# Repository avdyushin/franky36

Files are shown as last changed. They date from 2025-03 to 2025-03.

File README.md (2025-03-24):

# Franky36

Franky36 is 36 key compact handwired split keyboard.
It uses RP2040-Zero controller and QMK firmware.

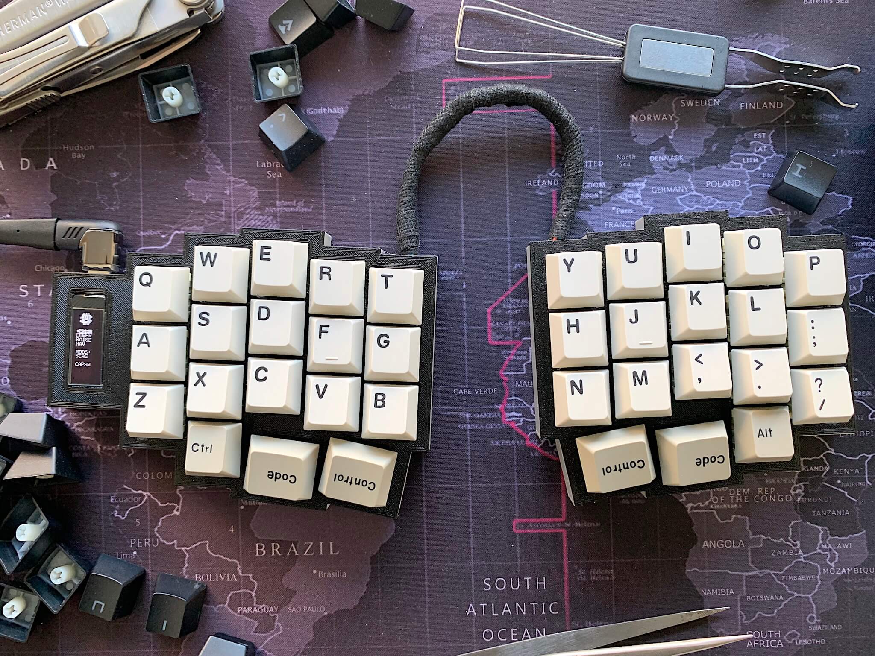
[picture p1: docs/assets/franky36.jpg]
franky36


GMK 9009 clone PBT keycaps are used in the photo.

## Features

- Split with single controller
- QMK (fully customizable)
- VIA support
- OLED display with layer status
- USB-C

## Layout

The default layout is similar to the Planck layout.

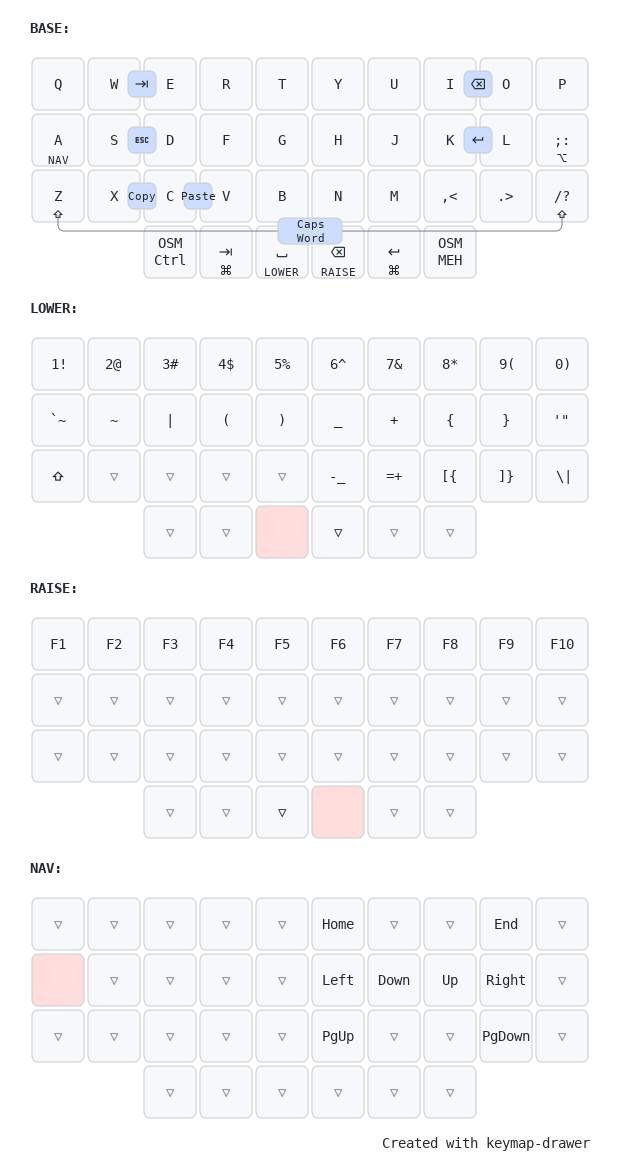
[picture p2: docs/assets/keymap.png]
layout


## Bill Of Material

| Item | Quantity |
|---|---|
| 3D printed case parts | 6 |
| RP2040-Zero controller | 1 |
| MX switches | 36 |
| Through hole 1N4148 diodes | 36 |
| OLED 128x32 SSD1306 display | 1 |
| 1u keycaps | 32 |
| 1.25u keycaps | 4 |
| Electrical wires | |
| Magnetic USB-C adapter (optional) | 1 |
| Foam | 1 |

## Case and Plate

Designed in OpenSCAD and 3D printed. See [case](./case) for STL files and OpenSCAD source.

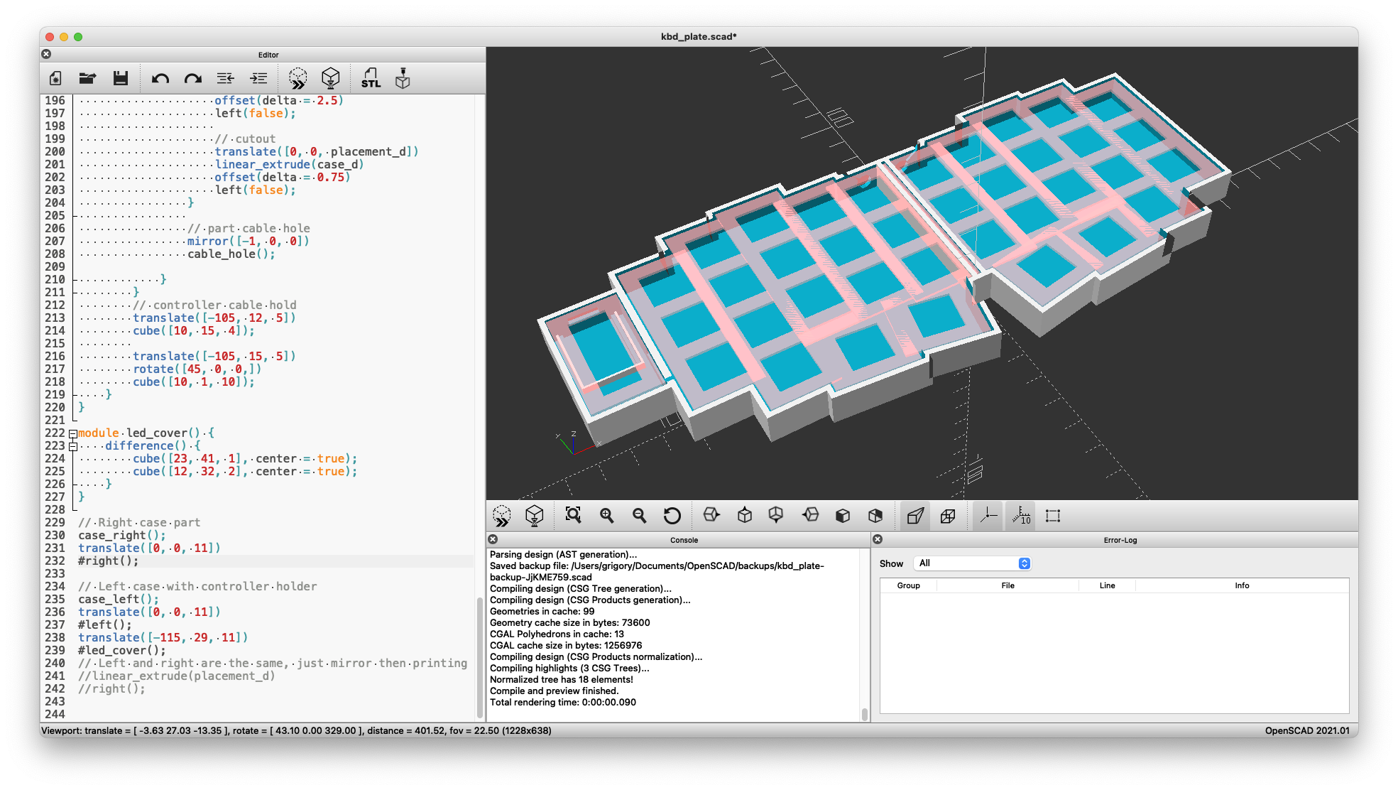
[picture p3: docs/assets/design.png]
case


## Assembly

Assembling the Franky36 keyboard involves several steps that require attention to detail and precision.
This guide will walk you through each step of the process.
Before starting, make sure you have all the necessary components and tools listed in the Bill of Material section.

### Pinout

Rows and columns are connected to the RP2040-Zero controller as follows:

Columns: `GP9`, `GP10`, `GP11`, `GP12`, `GP13`, `GP14`, `GP15`, `GP26`, `GP27`, `GP28`

Rows: `GP5`, `GP4`, `GP3`, `GP2`

Display: `GP0` (SDA), `GP1` (SCL), `GND`, `3v3`

### Steps

1. Begin by printing case parts, plates, and covers. Ensure that the prints are accurate and fit together properly.
1. Insert the MX switches into the designated slots on the plates. Make sure each switch is securely in place.
1. Solder the through-hole 1N4148 diodes to the switches. This step is crucial for the proper functioning of the keyboard matrix.
1. Attach electrical wires to the switches. These wires will connect the switches to the controller.
1. Insert foam into the case to provide cushioning and reduce noise.
1. Carefully place the plates with the switches into the case, ensuring they fit snugly.
1. Connect the wires from the matrix to the RP2040-Zero controller by soldering them in place.
1. Solder OLED 128x32 SSD1306 display to the controller.
1. Secure the RP2040-Zero controller inside the case with hot glue.
1. Upload the QMK firmware to the controller.
1. Test the keyboard to ensure all keys and the OLED display are working as expected.
1. Place the cover on the case, carefuly put display into cutout.
1. Finally, place the keycaps.

## Firmware

QMK with VIA support. See [firmware](./firmware) folder for firmware binary files.

Source code is available in the [QMK firmware repository](https://github.com/qmk/qmk_firmware/tree/master/keyboards/handwired/franky36).

### QMK Configurator

You can use the [QMK Configurator](https://config.qmk.fm/#/handwired/franky36/LAYOUT) to create your custom keymap.

### VIA

Keymap with VIA support is available in the [QMK userspace repository](https://github.com/avdyushin/qmk_userspace_via/tree/franky36).

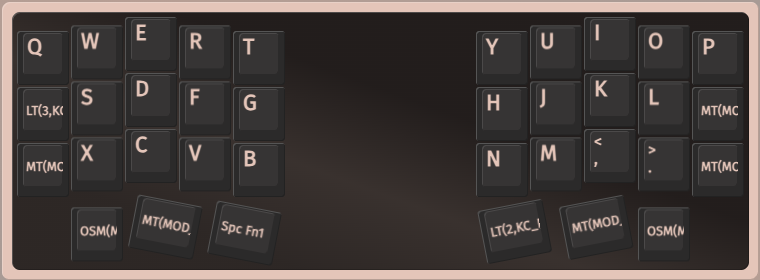
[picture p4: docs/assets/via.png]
via


VIA keyboard definition file is available in the [VIA repository](https://github.com/avdyushin/keyboards/tree/franky36/v3/handwired/franky36)

> NOTE: To make VIA export work in Brave browser enable File System Access API: brave://flags/#file-system-access-api

## Links

- [QMK](https://qmk.fm/)
- [VIA](https://caniusevia.com/)

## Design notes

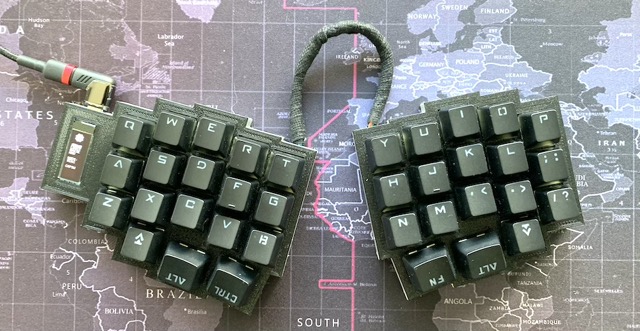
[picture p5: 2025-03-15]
docs/assets/completed.jpeg

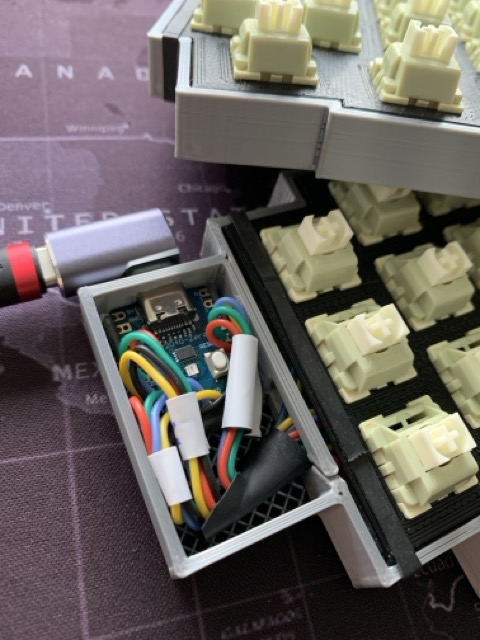
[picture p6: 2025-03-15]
docs/assets/case.jpeg

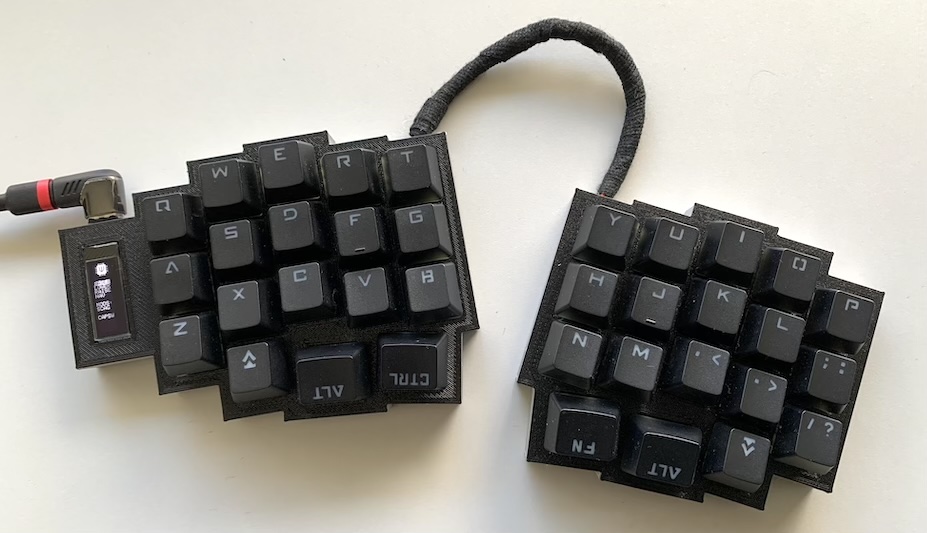
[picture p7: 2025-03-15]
docs/assets/franky36_black.jpg

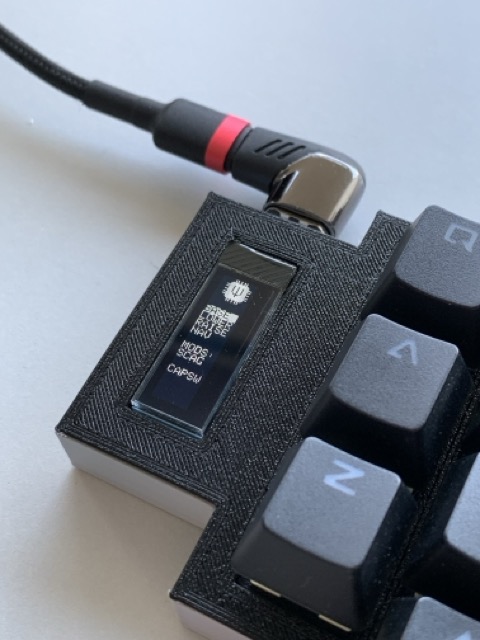
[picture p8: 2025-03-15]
docs/assets/display.jpeg

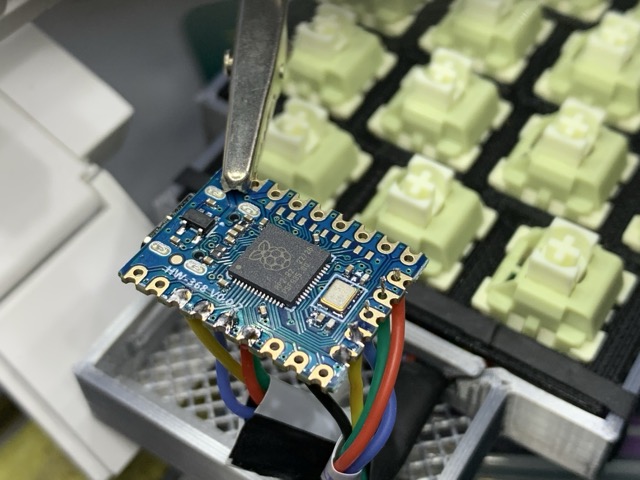
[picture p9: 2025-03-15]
docs/assets/controller.jpeg

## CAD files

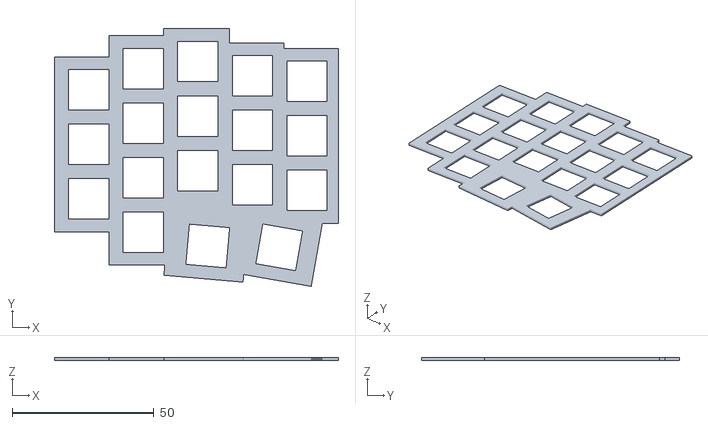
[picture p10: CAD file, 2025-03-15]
case/plate_left.stl
100.2 x 91.0 x 1.00

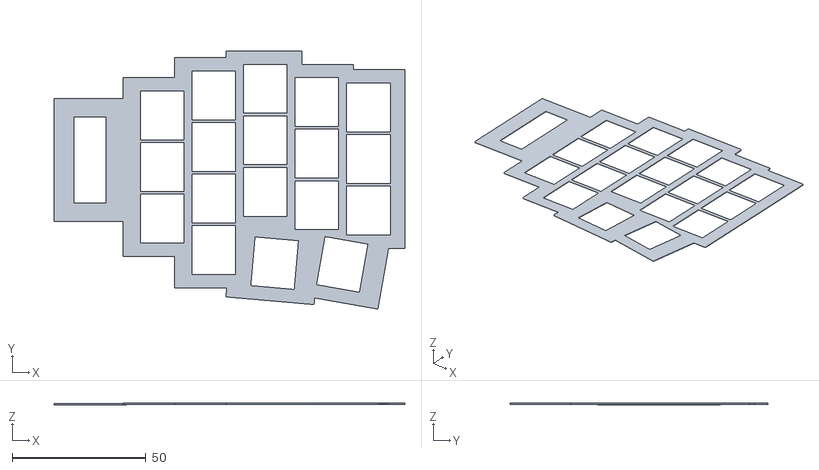
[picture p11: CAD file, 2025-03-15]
case/cover_left.stl
131.0 x 96.4 x 0.59

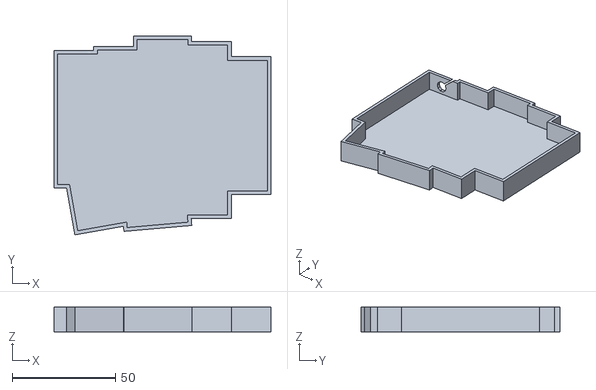
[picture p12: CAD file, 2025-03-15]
case/case_right.stl
105.2 x 96.4 x 12.0

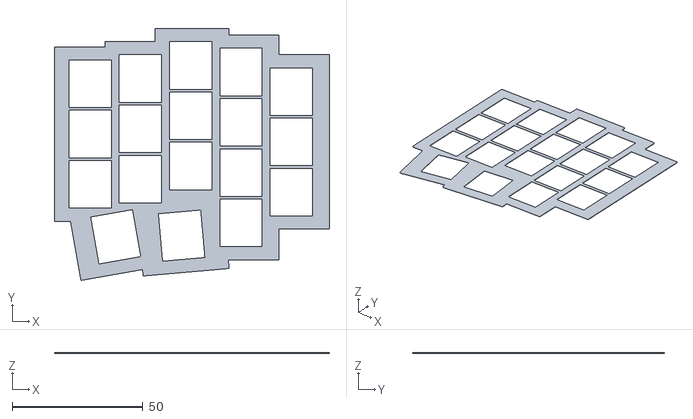
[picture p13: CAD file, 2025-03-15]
case/cover_right.stl
105.2 x 96.4 x 0.56

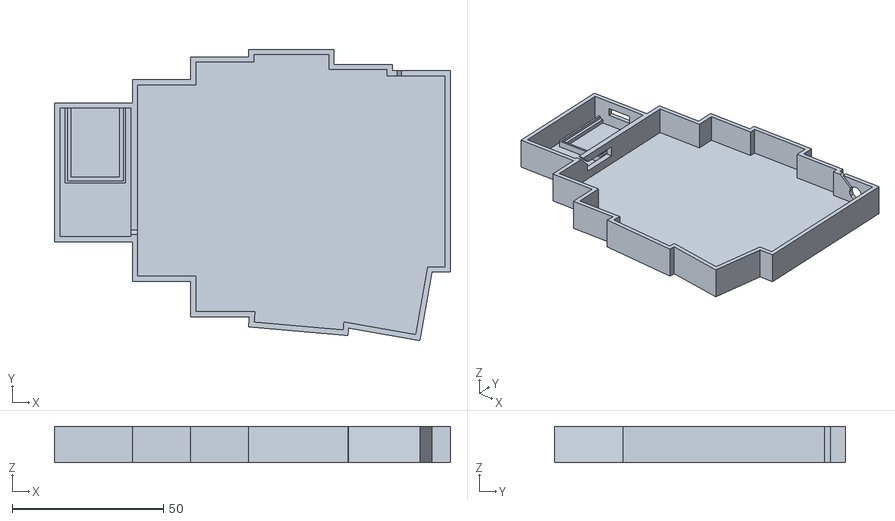
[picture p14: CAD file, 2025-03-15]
case/case_left.stl
131.0 x 96.4 x 12.0

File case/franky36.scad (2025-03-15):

mx_w = 14.25;
mx_h = 14.25;
mx_d = 10;

col_keys_count = 3;
col_keys_spacing_w = 2.5;
col_keys_spacing_h = 2.5;

placement_w = mx_w + col_keys_spacing_w * 2;
placement_h = mx_h + col_keys_spacing_h * 2;
placement_d = 1.5;
placement_padding = 2;

case_d = 12;

_1U = 1.0;
_1_25U = 1.25;

pro_micro_w = 18;
pro_micro_h = 33;

micro_usb_w = 8;
micro_usb_h = 3;

rp2040_zero_w = 18.5;
rp2040_zero_d = 24.5;
rp2040_zero_h = 1.5;

usb_c_w = 10;
usb_c_h = 3;

module switch_cutout() {
    square([mx_w, mx_h]);
}

module over_switch_cutout() {
    translate([-1, -2, 0])
    square([mx_w + 2, mx_h + 4]);
}

module switch_cuts_only(count, col_w) {
    dx0 = placement_padding + (col_w / 2 - (placement_w / 2));
    dy0 = placement_padding;
    
    
    translate([dx0, dy0])
    for (i = [0:1:count - 1]) {
        dy = col_keys_spacing_h + placement_h * i;
        translate([0, dy, 0])
            children();
    }
}

module keys_col(count, size = _1U, extra_pad = 0, offset_delta = 0) {
    col_h = count * placement_h + placement_padding * 2;
    col_w = placement_w * size + placement_padding * 2;

    if (offset_delta > 0) {
        switch_cuts_only(count, col_w) children();
    } else {
        difference() {
            union() {
                square([col_w, col_h]);
                
                // plug the hole
                translate([0, -extra_pad])
                square([col_w, extra_pad]);
            }
            switch_cuts_only(count, col_w) children();
        }
    }
}

module rows(offset_delta = 0) {
    row_offsets = [-2, 0, 5, 2.5 - placement_h, -5];
    col_counts = [3, 3, 3, 4, 3];
    extra_pads = [0, 0, 5, 0, 0];
    rows_count = len(row_offsets);

    for (i = [0:1:rows_count - 1]) {
        dx0 = placement_w * i;
        dy0 = row_offsets[i];
        count = col_counts[i];
        pad = extra_pads[i];
        translate([dx0, dy0, 0])
            keys_col(count, _1U, pad, offset_delta) children();
    }
}

module shift_key(offset_delta = 0) {
    translate([placement_w / 2, -placement_h - placement_padding * 2.5, 0])
    rotate([0, 0, 10])
    keys_col(1, _1_25U, 0, offset_delta) children();
}


module layer_key(offset_delta = 0) {
    translate([placement_w * 1.75, -placement_h - placement_padding * 1.75, 0])
    rotate([0, 0, 5])
    keys_col(1, _1_25U, 0, offset_delta) children();
}

module half(offset_delta = 0) {
    rows(offset_delta) children();
    shift_key(offset_delta) children();
    layer_key(offset_delta) children();
}

module left_plate(offset_delta = 0) {
    mirror([-1, 0, 0])
    half(offset_delta) children();
}

module right_plate(offset_delta = 0) {
    half(offset_delta) children();
}

module cable_hole() {
    union() {
        translate([placement_w / 2 - 2, placement_h * 3 + 10, 6])
        rotate([90, 0, 0])
        cylinder(h = 10, r = 3);
        
        rotate([0, 50, 0])
        translate([placement_w / 2 - 10, placement_h * 3, 10])
        cube([1, 15, 10]);
    }
}

module case_right() {
    
    difference() {
        difference() {
            // base
            linear_extrude(case_d)
            offset(delta = 2.5)
            right_plate();
            
            // cutout
            translate([0, 0, placement_d])
            linear_extrude(case_d)
            offset(delta = 0.75)
            right_plate();
        }
        
        // cable hole
        cable_hole();
    }
}

module plate() {
    cube([rp2040_zero_w, rp2040_zero_d, rp2040_zero_h]);
}

module plate_holder() {
    difference() {
        cube([20, 25, 4]);
        translate([2, -1, -0.5])
        cube([16, 24, 5]);
        translate([0.75, -0.25, 3]) plate();
    }
}

module controller_case() {
    
    c_w = pro_micro_w + placement_padding * 2;
    c_h = pro_micro_h + placement_padding * 4;
    
    difference() {
        // base
        linear_extrude(case_d)
        offset(delta = 2.5)
        square([c_w, c_h]);
        
        // cutout
        translate([0, 0, placement_d])
        linear_extrude(case_d)
        offset(delta = 0.75)
        square([c_w, c_h]);
        
        // usb hole
        translate([c_w / 2 - usb_c_w / 2, c_h, 6])
        cube([usb_c_w, 5, usb_c_h]);
    }
    rotate([0, 0, 180])
    translate([-21, -42, 0])
        plate_holder();
}


module case_left() {
    difference() {
        union() {
            translate([-126, 8, 0])
            controller_case();
            difference() {
                difference() {
                    // base
                    linear_extrude(case_d)
                    offset(delta = 2.5)
                    left_plate();
                    
                    // cutout
                    translate([0, 0, placement_d])
                    linear_extrude(case_d)
                    offset(delta = 0.75)
                    left_plate();
                }
                
                // part cable hole
                mirror([-1, 0, 0])
                cable_hole();

            }
        }
        // controller cable hold
        translate([-105, 12, 5])
        cube([10, 15, 4]);
        
        translate([-105, 15, 5])
        rotate([45, 0, 0,])
        cube([10, 1, 10]);
    }
}

module led_cover(h) {
    difference() {
        cube([23, 41, h], center = true);
        cube([12, 32, h * 2], center = true);
    }
}

module led_top_cover(h) {
    difference() {
        cube([27, 46, h], center = true);
        cube([12, 32, h * 2], center = true);
    }

}

module right_top_cover() {
    difference() {
        linear_extrude(4)
        offset(delta = 5)
        right_plate();
        translate([0, 0, -1])
        linear_extrude(4)
        offset(delta = 3.5)
        right_plate();
        
        translate([0, 0, 1])
        linear_extrude(4)
        right_plate(offset_delta = 1) over_switch_cutout();
    }
}

module right_top_cover_v2(h) {
    difference() {
        linear_extrude(h)
        offset(delta = 2.5)
        right_plate();
        
        translate([0, 0, -1])
        linear_extrude(h + 2)
        right_plate(offset_delta = 1) over_switch_cutout();
    }
}

module left_top_cover_v2(h) {
    union() {
        difference() {
            linear_extrude(h)
            offset(delta = 2.5)
            left_plate();
            
            translate([0, 0, -1])
            linear_extrude(h + 2)
            left_plate(offset_delta = 1) over_switch_cutout();
        }

        translate([-115, 28.5, 0.25])
        led_top_cover(h);
    }
}

// Right case part
//case_right();
//translate([0, 0, 11])
//linear_extrude(1) right_plate() switch_cutout();

//#case_right();
//translate([0, 0, 11])
//#right_plate() switch_cutout();
//translate([0, 0, 13])
//right_top_cover_v2(h = 0.56);


// Left case with controller holder
//case_left();
//translate([0, 0, 11])
linear_extrude(1) left_plate() switch_cutout();
//translate([-115, 29, 11])
//#led_cover(h = 1);
//
//translate([0, 0, 13])
//left_top_cover_v2(h = 0.56);


// Left and right are the same, just mirror then printing, for example:
//linear_extrude(placement_d)
//right_plate() switch_cutout();

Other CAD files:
case/plate_right.stl

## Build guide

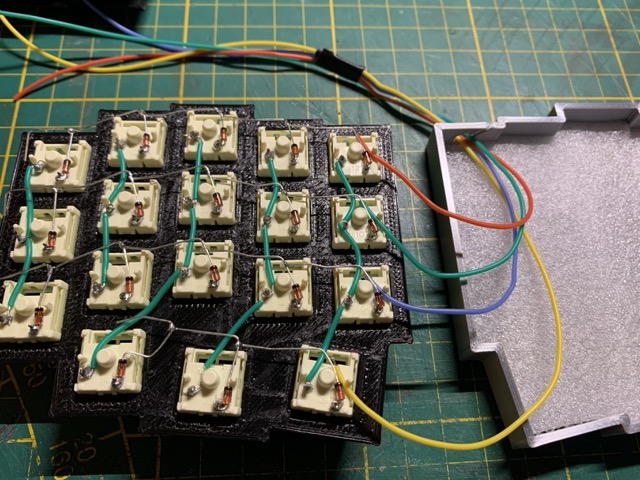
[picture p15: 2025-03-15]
docs/assets/wiring.jpeg
